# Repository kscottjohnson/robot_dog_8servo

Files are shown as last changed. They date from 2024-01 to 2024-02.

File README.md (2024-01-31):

# robot_dog_8servo
work in progress

Robot Dog - 8 servos

Built using:

Adafruit Feather nRF52840 Sense https://www.adafruit.com/product/4516

Adafruit 8-Channel PWM https://www.adafruit.com/product/2928

Petoi P1S Servos https://www.petoi.com/products/quadruped-robot-dog-bittle-servo-set

CAD Files: https://cad.onshape.com/documents/8333173851597a9055907f1a/w/0d3396945243be87c12bd9f1/e/d1048b7d1b790c7449558c67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

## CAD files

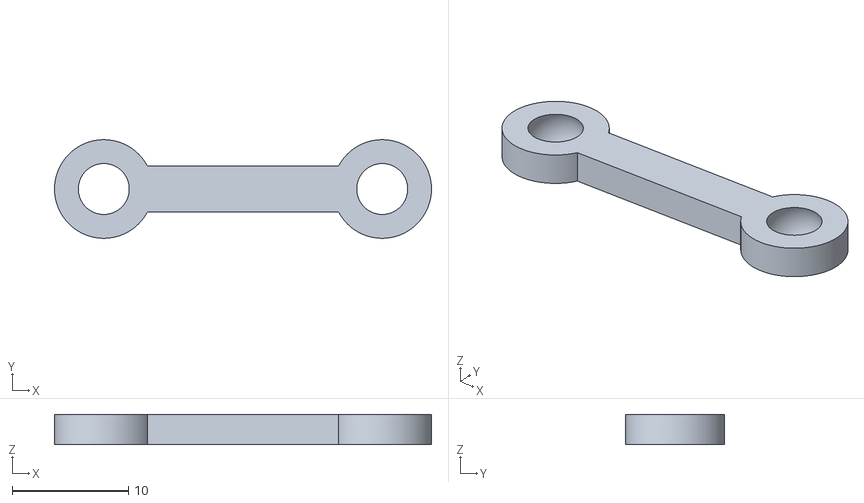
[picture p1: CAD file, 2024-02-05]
stl/Leg Parts - Smol Tendon.stl
32.5 x 8.50 x 2.60

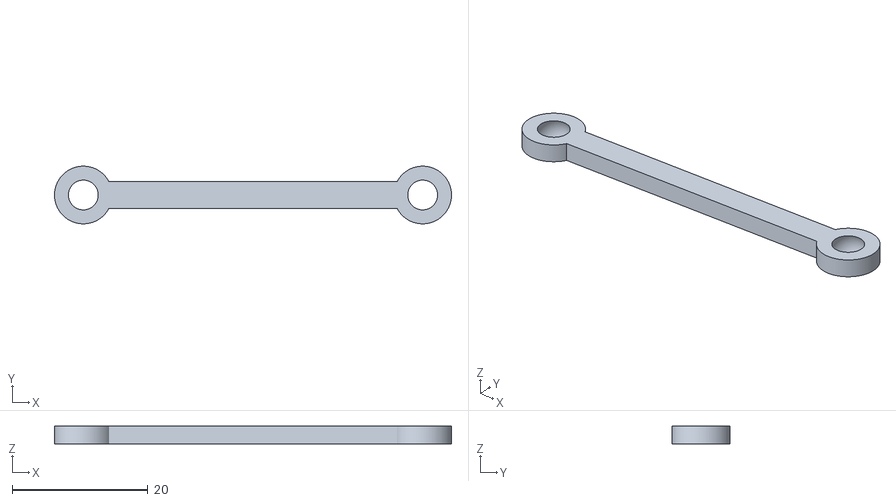
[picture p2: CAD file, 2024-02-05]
stl/Leg Parts - Long Tendon.stl
58.5 x 8.50 x 2.60

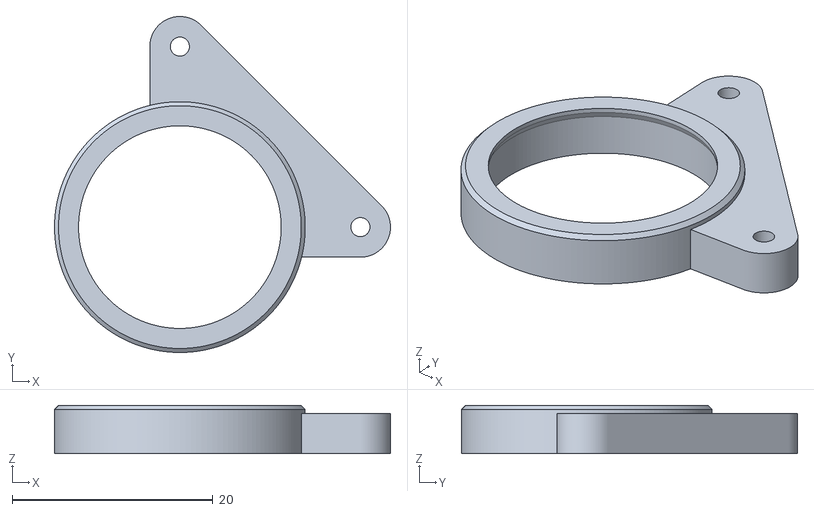
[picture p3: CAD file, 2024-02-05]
stl/Leg Parts - Shoulder.stl
33.5 x 33.5 x 4.80

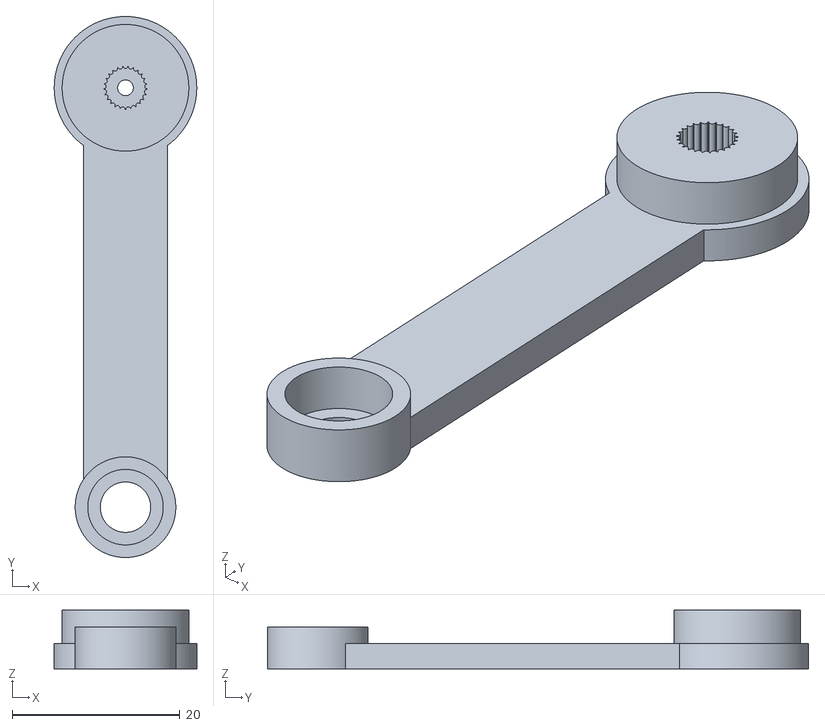
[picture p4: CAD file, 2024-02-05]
stl/Leg Parts - Upper Leg.stl
17.0 x 64.5 x 7.00

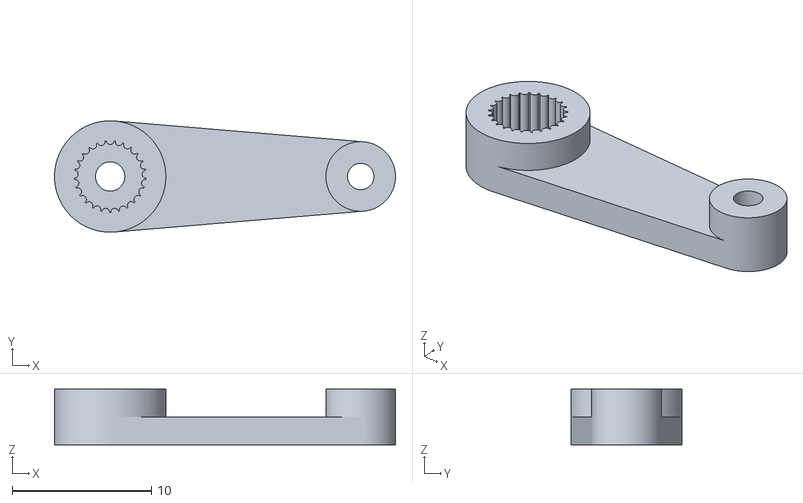
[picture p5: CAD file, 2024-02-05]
stl/Leg Parts - Servo Horn Lever.stl
24.5 x 8.00 x 4.00

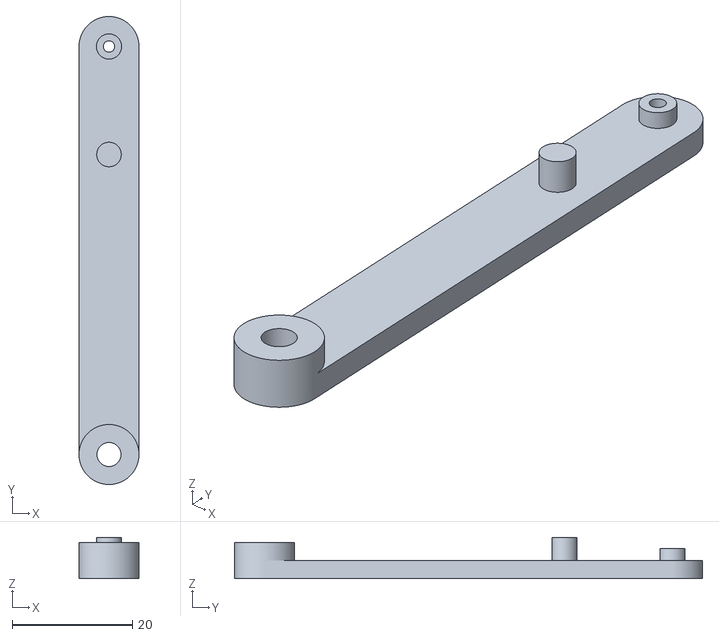
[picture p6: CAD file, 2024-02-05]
stl/Leg Parts - Lower Leg.stl
10.0 x 78.0 x 6.90

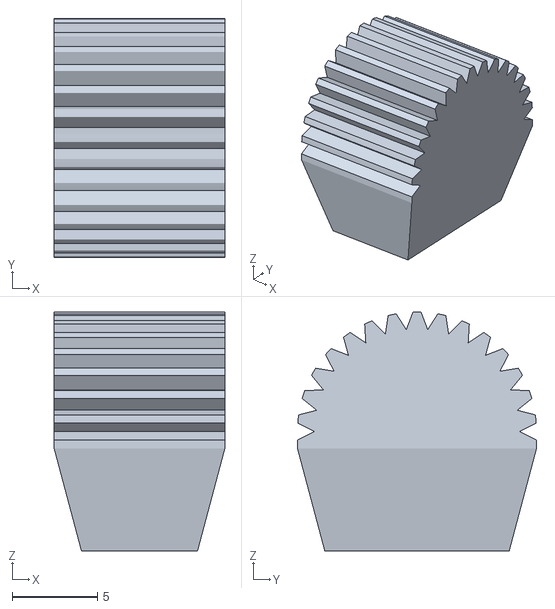
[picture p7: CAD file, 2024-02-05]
stl/Leg Parts - Boot.stl
10.0 x 14.0 x 14.0

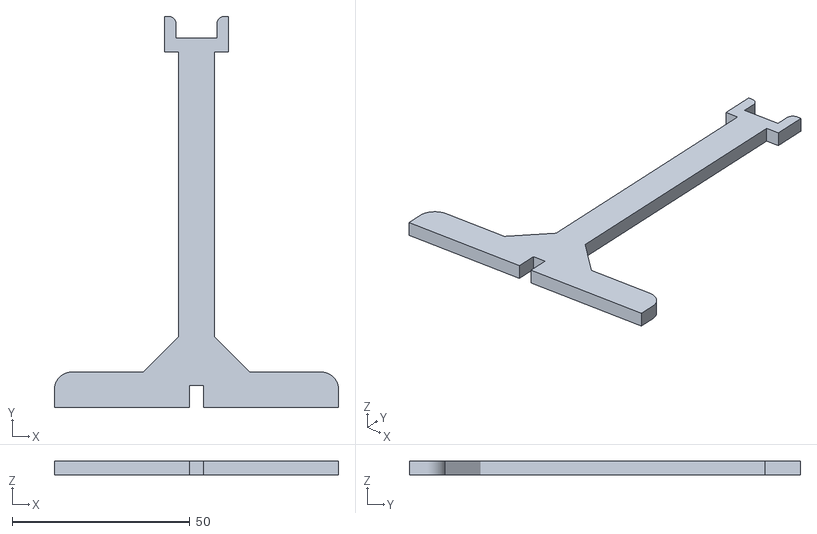
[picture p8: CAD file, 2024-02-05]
stl/Stand Parts - Stand Trunk.stl
80.0 x 110.0 x 4.00

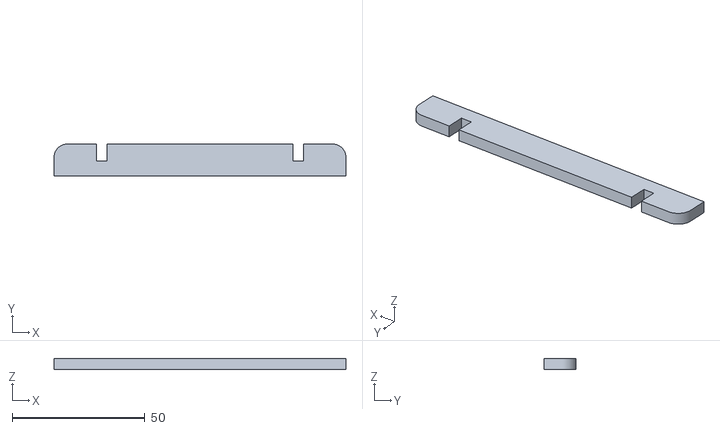
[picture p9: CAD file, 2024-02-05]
stl/Stand Parts - Stand Base.stl
110.0 x 12.0 x 4.00

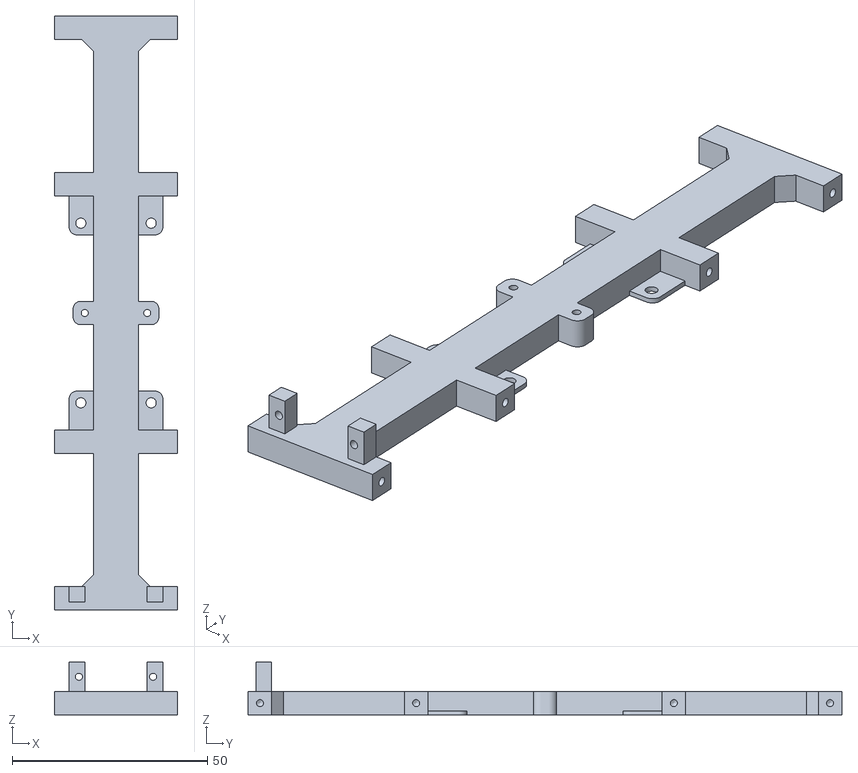
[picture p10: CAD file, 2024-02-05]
stl/Body Parts - Frame.stl
31.5 x 152.0 x 13.5

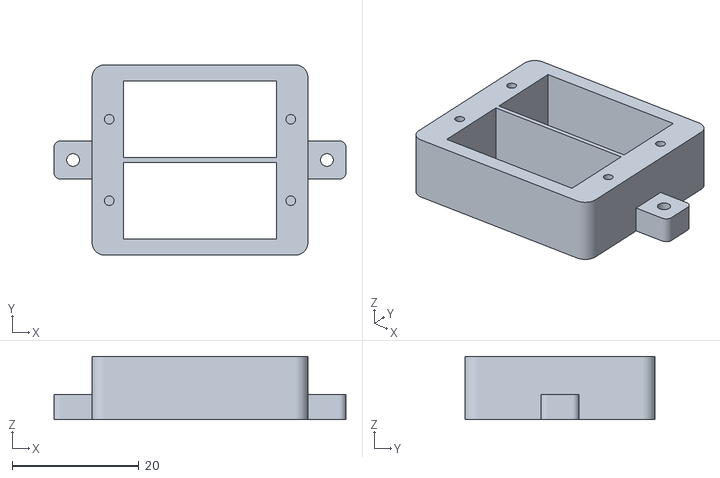
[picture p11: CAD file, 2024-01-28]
stl/Body Parts - Leg Joint.stl
46.0 x 30.0 x 10.0

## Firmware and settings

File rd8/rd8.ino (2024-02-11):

#include <Wire.h>
#include <Adafruit_PWMServoDriver.h>
#include <bluefruit.h>

#define FRONT_LEFT 0
#define FRONT_RIGHT 1
#define BACK_LEFT 2
#define BACK_RIGHT 3
#define FEMUR 50

#include "LegServo.h"

// Servos
Adafruit_PWMServoDriver driver = Adafruit_PWMServoDriver(0x40);

LegServo servos[8] = { // 270 degrees pwm 100 to 505
  LegServo(&driver, 6, 228,  90), // Front Left Hip - 0 degrees is forward - 235
  LegServo(&driver, 7, 126,  22), // Front Left Knee - 0 degrees is vertical - 145
  LegServo(&driver, 4, 363, 180), // Front Right Hip - 270 degrees is forward - 370
  LegServo(&driver, 5, 470, 248), // Front Right Knee - 270 degrees is vertical - 460
  LegServo(&driver, 0, 238,  90), // Back Left Hip
  LegServo(&driver, 1, 136,  22), // Back Left Knee
  LegServo(&driver, 2, 370, 180), // Back Right Hip
  LegServo(&driver, 3, 459, 248), // Back Right Knee
};

Leg legs[4] = {
  Leg(&servos[0], &servos[1], false, 2), // Front Left
  Leg(&servos[2], &servos[3], true,  2), // Front Right
  Leg(&servos[4], &servos[5], false, 2), // Back Left
  Leg(&servos[6], &servos[7], true,  2), // Back Right
};

// Bluetooth
BLEUart bleuart;
uint8_t controlMsg[6] = {128,128,128,128,0,0};
uint8_t rx, ry, lx, ly;
bool buttonAR, buttonBR, buttonCR, buttonR, buttonL;
uint8_t mode = 0;

#define CLOCK_CYCLE 5
unsigned long currentMs;
unsigned long prevMs;
unsigned long connectedMs;

void setup() {
  Serial.begin(115200);
  //while (!Serial) yield();
  Serial.println("Robot Dog - 8 Servo");

  // start servos
  driver.begin();
  driver.setOscillatorFrequency(25000000);
  driver.setPWMFreq(50);

  delay(100);
  //centerServos();
  stand();
  delay(100);

  startBleAdv();

  delay(500);

  prevMs = millis();
}

void loop() {
  currentMs = millis();
  if((currentMs - prevMs) < CLOCK_CYCLE) return;
  prevMs = currentMs;

  if(! Bluefruit.Periph.connected()){
    Serial.println("Not Connected");
    stand();
    delay(1000);
    return;
  }
  if((currentMs - connectedMs) < 1000){ // wait a second after connecting
    return;
  }

  //centerServos();
  //stand();
  //lay();
  //balanceTest();
  //trotInPlace();
  //staticWalk();

  //Serial.print("Mode "); Serial.print(mode);
  if(mode == 0) stand();
  else if(mode == 1) demo();
  else if(mode == 2) staticWalk();
  else stand();

}

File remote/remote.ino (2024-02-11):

#include <SPI.h>
#include <Wire.h>
#include <Adafruit_GFX.h>
#include <Adafruit_SH110X.h>
#include <bluefruit.h>

BLEClientUart clientUart;
uint8_t controlMsg[6] = {128,128,128,128,0,0};

Adafruit_SH1107 display = Adafruit_SH1107(64, 128, &Wire);

#define BUTTON_A  9
#define BUTTON_B  6
#define BUTTON_C  5
#define BUTTON_R 10
#define BUTTON_L 11
#define JOYRX A0
#define JOYRY A1
#define JOYLX A2
#define JOYLY A3
#define BATT_PIN A6

uint8_t mode = 0;
uint8_t lx, ly, rx, ry;
bool buttonA, buttonB, buttonC, buttonR, buttonL;
uint8_t remoteBatt;

//calibration
uint16_t lxMin = 935, lxMax = 0, lyMin = 0, lyMax = 936;
uint16_t rxMin = 936, rxMax = 0, ryMin = 0, ryMax = 935;

unsigned long currentMs;
unsigned long prevMs;

void setup() {
  Serial.begin(115200);
  Serial.println("rd8 remote");

  pinMode(BUTTON_A, INPUT_PULLUP);
  pinMode(BUTTON_B, INPUT_PULLUP);
  pinMode(BUTTON_C, INPUT_PULLUP);
  pinMode(BUTTON_R, INPUT_PULLUP);
  pinMode(BUTTON_L, INPUT_PULLUP);

  setControls();
  
  setupDisplay();

  startBleScan();

  remoteBatt = readBatt();

  prevMs = millis();
}

void loop() {
  currentMs = millis();
  if(currentMs - prevMs < 50) return;
  prevMs = currentMs;

  if(!digitalRead(BUTTON_A)){
    if(++mode == 3) mode = 0; // cycle mode
    while(!digitalRead(BUTTON_A)){ // pause until button released
      delay(100);
    }
  }

  setControls();

  sendControls();

  remoteBatt = smooth(remoteBatt, readBatt(), 10);

  refreshDisplay();
}

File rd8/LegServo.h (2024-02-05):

#ifndef LegServo_h
#define LegServo_h

class LegServo {
  public:
    LegServo(Adafruit_PWMServoDriver* driver, uint8_t num, uint16_t defaultPWM, 
      uint16_t defaultAngle);
    void setDefault();
    void setAngle(float ang);
  private:
    Adafruit_PWMServoDriver* _driver;
    uint8_t _num;
    uint16_t _defaultPWM;
    uint16_t _defaultAngle;
    void _setPWM(uint16_t pwm);
};

LegServo::LegServo(Adafruit_PWMServoDriver* driver, uint8_t num, uint16_t defaultPWM, 
  uint16_t defaultAngle){
  
  _driver = driver;
  _num = num;
  _defaultPWM = defaultPWM;
  _defaultAngle = defaultAngle;
}

void LegServo::_setPWM(uint16_t pwm){
  this->_driver->setPWM(this->_num, 0, pwm);
}

void LegServo::setDefault(){
  this->_setPWM(this->_defaultPWM);
}

void LegServo::setAngle(float ang){
  uint16_t pwm = (ang - this->_defaultAngle) * 1.5 + this->_defaultPWM;
  this->_driver->setPWM(this->_num, 0, pwm);
}

class Leg {
  public:
    Leg(LegServo* hipServo, LegServo* kneeServo, bool reverseLeg, float xAdj);
    LegServo* hip;
    LegServo* knee;
    void setDefault();
    void setAngles(float h, float k);
    bool isReversed();
    void move(float x, float y);
  private:
    bool _reverseLeg;
    float _xAdj;
};

Leg::Leg(LegServo* hipServo, LegServo* kneeServo, bool reverseLeg, float xAdj){
  hip = hipServo;
  knee = kneeServo;
  _reverseLeg = reverseLeg;
  _xAdj = xAdj;
}

void Leg::setDefault(){
  this->hip->setDefault();
  this->knee->setDefault();
}


float adjacentAngle(float a) {
  // gets the adjacent angle in a specified quadrilateral with sides 24,18,18,18

  return (
    (
      acos((648.0-648.0*cos(a*DEG_TO_RAD))/(36.0*sqrt(648.0-648.0*cos(a*DEG_TO_RAD)))) +
      acos((396.0-648.0*cos(a*DEG_TO_RAD))/(36.0*sqrt(648.0-648.0*cos(a*DEG_TO_RAD))))
    )
    *RAD_TO_DEG
  );
}

void Leg::setAngles(float h, float k){
  //Serial.print("setting angles "); 
  //Serial.print(h); Serial.print(" "); 
  //Serial.println(k);

  float k2 = adjacentAngle(-1 * (k + h - 315)) - 45;

  //Serial.print("servo angles "); 
  //Serial.print(h); Serial.print(" "); 
  //Serial.println(k2);

  if(this->isReversed()){
    this->hip->setAngle(270-h); 
    this->knee->setAngle(270-k2);
  }
  else{
    this->hip->setAngle(h); 
    this->knee->setAngle(k2);
  }
}

bool Leg::isReversed() {
  return this->_reverseLeg;
}

void Leg::move(float x, float y){

  // adjust x for calibration
  x += this->_xAdj;

  // find the lenght of the leg given the x and y measurments
  float legLen = sqrt(x*x+y*y);

  // find the knee angle using the law of cosines and the leg and femur length
  //float kneeAngle = acos((legLen*legLen-2*FEMUR*FEMUR)/(-2*FEMUR*FEMUR))*RAD_2_DEG;
  float kneeAngle = asin(legLen/2/FEMUR)*2*RAD_TO_DEG;

  // find the first part of the hip angle using the same triangle
  float h1 = (180 - kneeAngle) / 2;

  // 2nd part of hip 
  float h2 = 90;
  if(x != 0){
    h2 = acos(x/legLen)*RAD_TO_DEG;
  }

  float hipAngle = h1 + h2;

  this->setAngles(hipAngle, kneeAngle);
}
#endif

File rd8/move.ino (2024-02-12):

// Leg calibration, movement and walking algorithms

void centerServos() {
  legs[FRONT_LEFT].setDefault();
  legs[FRONT_RIGHT].setDefault();
  legs[BACK_LEFT].setDefault();
  legs[BACK_RIGHT].setDefault();
}

void balanceTest() {
  legs[FRONT_LEFT ].move( 0, 60);
  legs[FRONT_RIGHT].move( 0, 70);
  legs[BACK_LEFT  ].move( 0, 70);
  legs[BACK_RIGHT ].move( 0, 60);
}

void trotInPlace(){
  legs[FRONT_LEFT ].move( 0, 70);
  legs[FRONT_RIGHT].move( 0, 60);
  legs[BACK_LEFT  ].move( 0, 60);
  legs[BACK_RIGHT ].move( 0, 70);
  delay(500);
  legs[FRONT_LEFT ].move( 0, 60);
  legs[FRONT_RIGHT].move( 0, 70);
  legs[BACK_LEFT  ].move( 0, 70);
  legs[BACK_RIGHT ].move( 0, 60);
  delay(500);
}

void stand() {
  for(uint16_t l = 0; l<4; l++){
    legs[l].move(0, 70);
  }
}

void lay() {
  for(uint16_t l = 0; l<4; l++){
    legs[l].move(10, 30);
  }
}

void demo() {

  //map left x axis to forward/backward
  float x = map(lx, 0, 255, -30, 30);
  //map left y axis to hight
  float y = map(ly, 0, 255, 30, 96);

  // map right x axis to roll
  float r = map(rx, 0, 255, -30, 30);
  // map right u axis to pitch
  float p = map(ry, 0, 255, -30, 30);

  legs[FRONT_LEFT ].move( x, y-p+r);
  legs[FRONT_RIGHT].move( x, y-p-r);
  legs[BACK_LEFT  ].move( x, y+p+r);
  legs[BACK_RIGHT ].move( x, y+p-r);
}

uint8_t sTick = 0;
uint8_t sTicksPerState = 8;
uint8_t sWalkState = 0;
float sCurrentX[4] = {0,0,0,0}, sCurrentY[4] = {70,70,70,70};
float    sPrevX[4] = {0,0,0,0},    sPrevY[4] = {70,70,70,70};
bool sFirstStep = true;
int8_t sDirection = 1; // 1 forward, -1 reverse
uint8_t sLegSpeed = 3; // multiplier for leg movement
uint8_t sWalkStyle = 0; // 0 - walk, 1 - trot
int8_t sWalkSpeed = 0;
int8_t sMaxWalkSpeed = 8;

const uint8_t sLegStateOffset[2][4] = { 
  {0,2,1,3}, // walk
  {0,2,2,0}  // trot
};
const int8_t sWalkX[32] = { // pattern repeats to make the offsets loop
  -7, 0, 7, 6, 5, 4, 3, 2, 1, 0,-1,-2,-3,-4,-5,-6,
  -7, 0, 7, 6, 5, 4, 3, 2, 1, 0,-1,-2,-3,-4,-5,-6
};
const int8_t sWalkY[32] = {
  70,45,70,70,70,70,70,70,70,70,70,70,70,70,70,70,
  70,45,70,70,70,70,70,70,70,70,70,70,70,70,70,70
};

void staticWalk() { // defines individual static movement for each leg
  
  if(sTick == 0){ // get walk speed at start of walk state
    sWalkSpeed = map(ly, 0, 255, -1 * sMaxWalkSpeed, sMaxWalkSpeed);

    if(sWalkSpeed != 0){
      sTicksPerState =  (float) sMaxWalkSpeed / abs(sWalkSpeed) * 4;
      if(sWalkSpeed > 0){
        sDirection = 1;
      }
      else{ 
        sDirection = -1;
      }
      if(abs(sWalkSpeed) > 4){ // trot if speed >= 5
        sWalkStyle = 1;
      }
      else{ 
        sWalkStyle = 0;
      }
    }
    else {
      sTicksPerState = 16; // for stationary spin
    }

  }
  
  if(sWalkSpeed == 0){

    for(uint8_t l=0; l<4; l++){
      sCurrentX[l] = 0;
      sCurrentY[l] = 70;
      sPrevX[l] = 0;
      sPrevY[l] = 70;

      legs[l].move(sCurrentX[l], sCurrentY[l]);
    }
    sTick = 0;
    sWalkState = 0;
    sDirection = 1;
    sFirstStep = true;
  }
  else{
    //moving
    //Serial.print(sWalkState);Serial.print(" ");Serial.println(sTick);
    for(uint8_t l=0; l<4; l++){
      uint8_t legState = sWalkState + 4 * sLegStateOffset[sWalkStyle][l];
      if(sTick + 1 == sTicksPerState){ // if this is the last tick just set the targets
        sCurrentX[l] = sWalkX[legState]*sLegSpeed;
        sCurrentY[l] = sWalkY[legState];
        sPrevX[l] = sCurrentX[l];
        sPrevY[l] = sCurrentY[l];
      }
      else{
        sCurrentX[l] += (sWalkX[legState]*sLegSpeed - sPrevX[l]) / sTicksPerState;
        sCurrentY[l] += (sWalkY[legState] - sPrevY[l]) / sTicksPerState;
      }
      if(sFirstStep && legState < 9){
        // hack to make non-lifting leg not go forward when starting
        sCurrentX[l] = 0; 
        sPrevX[l] = 0;
      }
      legs[l].move(sCurrentX[l], sCurrentY[l]);
    }

    if(++sTick == sTicksPerState){ // new state
      sTick = 0;
      sWalkState += sDirection;
      sFirstStep = false;
      if(sWalkState == 16){ // new cycle
        sWalkState = 0;
      }
      else if(sWalkState == 255){ // new cycle
        sWalkState = 15;
      }
    }
  }

  

}

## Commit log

2024-01-28 adding STL files
    [Body Parts - Frame.stl, Body Parts - Leg Joint.stl, Leg Parts - Knee Cap.stl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]
2024-01-30 added leg class
2024-02-02 updated knee servo calculation
2024-02-04 added leg movement calculation
2024-02-05 updated stl files
    [Body Parts - Frame.stl, Leg Parts - Boot.stl, Leg Parts - Knee Cap.stl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]
2024-02-05 added calibration to leg class
